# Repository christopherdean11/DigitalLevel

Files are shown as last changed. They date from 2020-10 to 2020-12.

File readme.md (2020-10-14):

# Digital LED Level
Custom PCB for using an accelerometer as a level with LED indicators. Scope is small to encourage getting to the finish line but has enough hardware features to come up with createive software ideas. 

## Goals
Overall: Create a PCB from scratch that can display multiple LED patterns  
- [x] Select a MCU - STM32F030F4
- [x] Design a PCB
- [x] Fab the PCB
- [x] Populate the PCB
- [x] Code and test the PCB

## Vender Documentation
### Datasheets:
* MCU - [STM32F030F4](https://www.st.com/resource/en/datasheet/stm32f030f4.pdf), [Reference Manual](https://www.st.com/resource/en/reference_manual/dm00091010-stm32f030x4x6x8xc-and-stm32f070x6xb-advanced-armbased-32bit-mcus-stmicroelectronics.pdf)
* 3.3V LDO - [MIC5504-3.3](https://www.microchip.com/wwwproducts/en/MIC5504)
* Accelerometer - [ADXL343](https://www.analog.com/media/en/technical-documentation/data-sheets/ADXL343.pdf)
* Acceleromter Breakout [Adafruit ADXL343 Breakout](https://learn.adafruit.com/adxl343-breakout-learning-guide/downloads)

### Guides / App Notes / Manuals:
* [STM32 Boot Options](https://www.st.com/content/ccc/resource/technical/document/application_note/b9/9b/16/3a/12/1e/40/0c/CD00167594.pdf/files/CD00167594.pdf/jcr:content/translations/en.C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)
* [Getting Started with STM32F030xx Hardware Development](https://www.st.com/content/ccc/resource/technical/document/application_note/91/66/2d/8c/f9/b5/47/55/DM00089834.pdf/files/DM00089834.pdf/jcr:content/translations/en.D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)
* [STM32F3 Discovery User Manual](https://www.st.com/content/ccc/resource/technical/document/user_manual/8a/56/97/63/8d/56/41/73/DM00063382.pdf/files/DM00063382.pdf/jcr:content/translations/en.DM0006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) (Initially used as a programmer, later replaced with standalone ST-LINK V2 USB dongle)

## Design Process
See [Hardware Design](pcb/readme.md) for hardware design process.  
Software Design readme coming soon.

## Features
#### Hardware
* 9 LEDs
* STM32F0
* Acceleromter
* 2 push-buttons
  - 1 hardwired to GPIO
  - 1 wired through a jumper to a GPIO (shared with INT1 on accelerometer)

#### Software
* LED cycle patterns with speed and direction adjustable with push-buttons

---
## Ideas for rev1
* Add a switch on the vcc input 
* Add smt LED on 3V3
* Just get the thing professionally assembled
* Would be nice to power from batteries, perhaps need a nice connector for that
* micro usb for power in connector?
* input voltage protection
* want to be able to control LED brightness
  - could try to find a suitable LED driver
  - could just add a PMOS inline with Vled for pwm-ing
  - could pwm the GPIOs but I don't think that would wok because PWM-ing the GPIO would block execution unless it was hardware timed somehow

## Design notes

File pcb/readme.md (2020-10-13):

# Hardware Design Process
## MCU Requirements
### Select an MCU
Initially thought about picking an STM32G0 series for low-cost, but after looking into it more, the STM32F0 series is not much more when buying low quantity, seems to be more popular, has extensive documentation, and the STM32F and STM32L series parts are already library components in Kicad.  
Another considerations was a package that lends itself to hand soldering.  With all of these in mind, I selected the [STM32F030F4](https://www.st.com/en/microcontrollers-microprocessors/stm32f030f4.html) in 20-pin TSSOP at approx. $1.23/unit.

###  I/O
This requires some time in STM Cube IDE to verify pinout and pin options to get a feel for what the board can look like.  We can easily get 8 GPIO outputs for LEDs with this MCU.  The [STM32F030F4](https://www.st.com/en/microcontrollers-microprocessors/stm32f030f4.html) comes in a 20pin TSSOP (this project will be hand soldered), with 12 GPIO available on PORTA + PB1 for 13 GPIO pins.
###  Programming
Another big item is how to program the MCU.  It looks like the STM32F030F4 has SWD (I beleive all ARM MCUs have this) support, so I should be able to connect with ST-LINK using SWD pins.  The F3 discovery board has an option to disconnect the actual dev board section from the ST-LINK section and use ST-LINK to program another board.  This will be a good starting point for programming. So the board will need to have the SWD pins broken out to headers.  

Tie BOOT0 to GND for normal operation and programming with SWD. See [this forum page](https://community.st.com/s/question/0D50X00009XkYDuSAN/hi-what-is-boot0-in-stm32).  Could tie it to a resitor to GND to leave door open to overdrive it if needed for some reason.  

The pinout for the SWD connector on the F3 Discovery board is available in [this document](https://www.st.com/content/ccc/resource/technical/document/user_manual/8a/56/97/63/8d/56/41/73/DM00063382.pdf/files/DM00063382.pdf/jcr:content/translations/en.DM0006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), page 16
Pins required: 
* VDD
* SWCLK
* GND
* SWDIO
* NRST - **NOTE:Solder bridge SB7 must be open to use NRST pin to control another device**

*Note: Eventually gave up with the F3 Discovery and orered a standalone ST-LINK V2 dongle, seems to just be easier*

## PCB Requirements:
- As small as reasonably possible to save cost
- series of LEDs in a row at one end
- SWD programming/debugging pins broken out
- At least 1 push button to cycle through LED options
- Acceleromter to do I2C comms and for LED patterns  

##  PCB Design Process:
* [x] Open CubeIDE to start a project with the STM32F030F4 and set up the pin configurations.
* [x] Add the MCU to a new design in Kicad.
* [x] Refer to the CubeIDE for the desired pin configuration.  Break out the SWD pins to headers and strap the BOOT pin.
* [x] Add some LEDs and a push button and wire it up.
* [x] Research and find an acceptable accelerometer.  Low cost I2C capable and hand-solerable.
* [x] Research and select a 3.3V regulator to power from 5V.

### Power
Plan is to power the board with 5V DC from a wall wart and regulate it to 3.3V.  Since this isn't powered by a battery, power efficiency isn't really a concern on this project (save that futuer versions), so an LDO will be fine, gets the job done and is dead simple to add to a PCB.  
#### Selecting 3.3V Regulator:
Just filter on digikey/mouser for 3.3V LDO. Found [MIC5504-3.3YM5](https://www.microchip.com/wwwproducts/en/MIC5504) for 3.3V at 300mA and 2% initial accuracy. VIN up to 5.5V. 
#### LED Power Consumption
9 LEDs at 15mA = 135mA  
Total allowed GPIO sourcing current for STM32F030F4 is 80mA (see page 44 in datasheet)  
*Redesigned board so LEDs are powered by the VDD rail and turned on off by GPIOs with an NMOS.*

### Acceleromoter
Needed a breakout board because all acceleromters have packages that do not lend themselves to hand-soldering.  The ADXL343 breakout from Adafruit is reasonbly priced and uses a quality acceleromter. 
Some notes: 
* Has a level shifter on board, may need to remove/jump over those but do not expect a problem
* See pg 16 of [ADXL3434 datasheet](https://www.analog.com/media/en/technical-documentation/data-sheets/ADXL343.pdf) for I2C addresses and address for Read/Write

| SDO/ALT_ADDRESS Pin | 7 bit address | Read Address | Write Address |  
| --- | --- | ---- | --- |
| GND | 0x53| 0xA6 | 0xA7 |

I2C address are 7-bit, and the least-signficant bit (LSB) is used to determine if the transaction is a read or write.

## PCB Layout
Begin layout of the design and revise as needed.
### Layout Process
1. Get everything in roughly the desired position. See how it looks, revise layout and schematic as needed.
   - I want all the LEDs in a nice row on the edge, so I changed the schematic to put LED current limit resistors between LED and NMOS and moved the current sense solder bridges for LED1 and LED5 for the same reason.  
1. Move on to routing power and ground after initial revisions are complete and rough layout is acceptable.
   - 2 Layer board
   - Ground plane as bottom layer, only use for routing when necessary to jump under existing traces
   - Run power along the edge of the board for LEDs and SW1, SW2, and wrap around to power acceleromter
   - This is not a high-speed or high-precision board, routing will be as good as it can be with 2 layers
## PCB Bring-Up Plan
Populate minimally requried components to get a program onto the board and show a sign of life.  
* Header pins, U1, U2, Boot resistor, decoupling caps, and LED2
* Run a program to blink LED2 to prove communication

Once that is working populate remainder of board and run a progressive blink routine to validate each LED.

## Experience Notes
* Almost forgot to add decoupling caps, researched and added those to the design as per the "Getting Started with STM32F030xx Hardware Development" link above.  
* Just noticed there is a "hand-solder" optional footprint for SMT components in KiCAD, and since I plan to hand solder, I will have to change all the footprints to those or I will probably wish I did.
* Board ordered on Feb 28 via oshpark
* Parts ordered on Feb 29 via mouser  

---

## Board Bring-up

*Eventually resolved these issues below and can talk to the board. Still not clear what the fix truly was, but I bought a standalone ST-LINK V2 USB dongle, updated STM CubeIDE to the latest, and completely discarded the Cube code project and started a Cube project, and all seems to be well.  The program downloads to the micro and the debugger works. Original debugging notes kept here.*

#### Original Debug Notes
* Trying to program using F3Discovery board as an ST-LINK and getting 

> Error message from debugger back end:  
> Load failed  
> Failed to execute MI command:  
> load /Users/christopherdean/Dev/stm32/LED_Level/code/Debug/Digital_Level.elf   
>  
> Error message from debugger back end:  
> Load failed  
> Load failed  

* Checked current on 3V3 rail (not using 3.3V regulator) and see it at ~1.3mA for a second or two, and then jump to ~1.8mA or 2mA
* [This schematic](https://easyeda.com/r3bers/STM32F103C8T6-Test-Board) shows pullup/down resistors on SWCLKS/SWDIO 
  - other posts online say the uc should have internal pullup/downs that are sufficient..

* Command to run the debugger from command line:
navigate to  
```
/Applications/STM32CubeIDE.app/Contents/Eclipse/plugins/com.st.stm32cube.ide.mcu.externaltools.stlink-gdb-server.macos64_1.3.0.202002181050/tools/bin
```
and run
```
./ST-LINK_gdbserver -d -v -cp /Applications/STM32CubeIDE.app/Contents/Eclipse/plugins/com.st.stm32cube.ide.mcu.externaltools.cubeprogrammer.macos64_1.3.0.202002181050/tools/bin
```

When I run it to program my board:
```
STMicroelectronics ST-LINK GDB server. Version 5.5.0
Copyright (c) 2019, STMicroelectronics. All rights reserved.

Starting server with the following options:
        Persistent Mode            : Disabled
        Logging Level              : 31
        Listen Port Number         : 61234
        Status Refresh Delay       : 15s
        Verbose Mode               : Enabled
        SWD Debug                  : Enabled

Target connection mode: Default
Target connection failed. Try connecting under reset
Target connection failed
Target unknown error 19

Error in initializing ST-LINK device.
Reason: Unknown. Please check power and cabling to target.
```

When I install the jumpers on the F3DISCOVERY board to use the ST-LINK to program the discovery board (and not just as an ST-LINK for external things), I see this:
```
STMicroelectronics ST-LINK GDB server. Version 5.5.0
Copyright (c) 2019, STMicroelectronics. All rights reserved.

Starting server with the following options:
        Persistent Mode            : Disabled
        Logging Level              : 31
        Listen Port Number         : 61234
        Status Refresh Delay       : 15s
        Verbose Mode               : Enabled
        SWD Debug                  : Enabled

Target connection mode: Default
Hardware watchpoint supported by the target 
COM frequency = 4000 kHz
ST-LINK Firmware version : V2J36M26
Device ID: 0x422
PC: 0x80007f8
ST-LINK device status: HALT_MODE
ST-LINK detects target voltage = 2.91 V
ST-LINK device status: HALT_MODE
ST-LINK device initialization OK
Waiting for debugger connection...
Waiting for connection on port 61234...
```
while it wait for a `gdb` process to connect to it

Maybe my microcontrollers are toasted?
Maybe next step is to solder one to a breakout board and try to program it on a breadboard?

Borrowed an STM32 USB programmer from a friend, got a new error about part is LOCKUP and debugger timed out.  Thought maybe finally clicking on the "Update CubeIDE" button might help. Get 1.4.2 installed and now the debugger won't even startup, just opens a window with 
```
ST-LINK Server is required to start the debug session. Download from st.com
```
Ok. Download. Install. No change. Restart the IDE. No change. :( 
This forum post suggests downgrading from 1.4.2 to 1.4.0 to get it to work. Ugh.
https://community.st.com/s/question/0D53W00000GWQKn/how-can-stlink-server-be-installed-for-use-by-stm32cubeide-

Tried to manually start the gdb session from the terminal with help here https://jacobmossberg.se/posts/2017/01/17/use-gdb-on-arm-assembly-program.html
it appeared to work and even saw `ST-LINK device status: RUN_MODE` but my board was still not working, perhaps a fundamental HW issue I just don't see. 

NRST pin is tied to the NRST pin on the SWD jumper but otherwise is floating.  It is supposed to be connected to a 40k ohm (typ) pullup internally.  There is a recommendation for a 0.1uF external capacitor to prevent parasitic resets, which is missing from the PCB design.  

#### Other Debugging Ideas
Maybe try the i2c lines as usart data lines for programming?
http://eleceng.dit.ie/frank/arm/STM32F030ISP/index.html

Maybe try after driving boot pin high:
https://electronics.stackexchange.com/questions/410386/stm32f0-boot0-pin-and-swd-programming

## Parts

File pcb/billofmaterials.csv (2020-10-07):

Id | Designator | Package | Quantity | Designation | Supplier and ref
1 | R10 | R_0603_1608Metric_Pad1.05x0.95mm_HandSolder | 1 | R
2 | R9,R8,R7,R6,R4,R3,R2,R1 | R_0603_1608Metric_Pad1.05x0.95mm_HandSolder | 8 | 100
3 | R5 | R_0603_1608Metric_Pad1.05x0.95mm_HandSolder | 1 | 82
4 | U3 | ADXL343_Breakout | 1 | ADXL343_Breakout
5 | U2 | SOT-23-5 | 1 | MIC5504-3.3YM5
6 | D9,D1,D2,D3,D4,D5,D6,D7,D8 | LED_D5.0mm | 9 | LED
7 | J1 | PinHeader_1x05_P2.54mm_Vertical | 1 | Conn_SWD
8 | J2 | PinHeader_1x02_P2.54mm_Vertical | 1 | Conn_VIN
9 | Q1,Q2,Q3,Q4,Q5,Q6,Q7,Q8,Q9 | SOT-23 | 9 | 2N7002
10 | SW1,SW2 | SW_PUSH_6mm | 2 | SW_Push
11 | U1 | TSSOP-20_4.4x6.5mm_P0.65mm | 1 | STM32F030F4Px
12 | J3 | PinHeader_1x03_P2.54mm_Vertical | 1 | Conn_SW_INT
13 | C1 | C_0603_1608Metric_Pad1.05x0.95mm_HandSolder | 1 | 100n
14 | C2 | C_1206_3216Metric_Pad1.42x1.75mm_HandSolder | 1 | 4.7u
15 | C3 | C_0603_1608Metric_Pad1.05x0.95mm_HandSolder | 1 | 10n
16 | C4 | C_1206_3216Metric_Pad1.42x1.75mm_HandSolder | 1 | 1u
17 | C5,C6 | C_0603_1608Metric_Pad1.05x0.95mm_HandSolder | 2 | 1u
18 | SB1,SB2 | R_0201_0603Metric | 2 | 0

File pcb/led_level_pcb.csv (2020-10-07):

Reference | Value | Footprint | Datasheet
U1 | STM32F030F4Px | Package_SO:TSSOP-20_4.4x6.5mm_P0.65mm | http://www.st.com/st-web-ui/static/active/en/resource/technical/document/datasheet/DM00088500.pdf
D1 | LED | LED_THT:LED_D5.0mm | ~
R10 | R | Resistor_SMD:R_0603_1608Metric_Pad1.05x0.95mm_HandSolder | ~
J1 | Conn_SWD | Connector_PinHeader_2.54mm:PinHeader_1x05_P2.54mm_Vertical | ~
SW1 | SW_Push | Button_Switch_THT:SW_PUSH_6mm
SW2 | SW_Push | Button_Switch_THT:SW_PUSH_6mm
U2 | MIC5504-3.3YM5 | Package_TO_SOT_SMD:SOT-23-5 | http://ww1.microchip.com/downloads/en/DeviceDoc/MIC550X.pdf
U3 | ADXL343_Breakout | footprints:ADXL343_Breakout
J3 | Conn_SW_INT | Connector_PinHeader_2.54mm:PinHeader_1x03_P2.54mm_Vertical | ~
R1 | 100 | Resistor_SMD:R_0603_1608Metric_Pad1.05x0.95mm_HandSolder | ~
Q1 | 2N7002 | Package_TO_SOT_SMD:SOT-23 | https://www.fairchildsemi.com/datasheets/2N/2N7002.pdf
Q2 | 2N7002 | Package_TO_SOT_SMD:SOT-23 | https://www.fairchildsemi.com/datasheets/2N/2N7002.pdf
D2 | LED | LED_THT:LED_D5.0mm | ~
D3 | LED | LED_THT:LED_D5.0mm | ~
Q3 | 2N7002 | Package_TO_SOT_SMD:SOT-23 | https://www.fairchildsemi.com/datasheets/2N/2N7002.pdf
Q4 | 2N7002 | Package_TO_SOT_SMD:SOT-23 | https://www.fairchildsemi.com/datasheets/2N/2N7002.pdf
D4 | LED | LED_THT:LED_D5.0mm | ~
R4 | 100 | Resistor_SMD:R_0603_1608Metric_Pad1.05x0.95mm_HandSolder | ~
Q5 | 2N7002 | Package_TO_SOT_SMD:SOT-23 | https://www.fairchildsemi.com/datasheets/2N/2N7002.pdf
D5 | LED | LED_THT:LED_D5.0mm | ~
R5 | 82 | Resistor_SMD:R_0603_1608Metric_Pad1.05x0.95mm_HandSolder | ~
D6 | LED | LED_THT:LED_D5.0mm | ~
R6 | 100 | Resistor_SMD:R_0603_1608Metric_Pad1.05x0.95mm_HandSolder | ~
Q6 | 2N7002 | Package_TO_SOT_SMD:SOT-23 | https://www.fairchildsemi.com/datasheets/2N/2N7002.pdf
Q7 | 2N7002 | Package_TO_SOT_SMD:SOT-23 | https://www.fairchildsemi.com/datasheets/2N/2N7002.pdf
D7 | LED | LED_THT:LED_D5.0mm | ~
R7 | 100 | Resistor_SMD:R_0603_1608Metric_Pad1.05x0.95mm_HandSolder | ~
D8 | LED | LED_THT:LED_D5.0mm | ~
R8 | 100 | Resistor_SMD:R_0603_1608Metric_Pad1.05x0.95mm_HandSolder | ~
Q8 | 2N7002 | Package_TO_SOT_SMD:SOT-23 | https://www.fairchildsemi.com/datasheets/2N/2N7002.pdf
Q9 | 2N7002 | Package_TO_SOT_SMD:SOT-23 | https://www.fairchildsemi.com/datasheets/2N/2N7002.pdf
D9 | LED | LED_THT:LED_D5.0mm | ~
R9 | 100 | Resistor_SMD:R_0603_1608Metric_Pad1.05x0.95mm_HandSolder | ~
R3 | 100 | Resistor_SMD:R_0603_1608Metric_Pad1.05x0.95mm_HandSolder | ~
R2 | 100 | Resistor_SMD:R_0603_1608Metric_Pad1.05x0.95mm_HandSolder | ~
J2 | Conn_VIN | Connector_PinHeader_2.54mm:PinHeader_1x02_P2.54mm_Vertical | ~
C1 | 100n | Capacitor_SMD:C_0603_1608Metric_Pad1.05x0.95mm_HandSolder | ~
C2 | 4.7u | Capacitor_SMD:C_1206_3216Metric_Pad1.42x1.75mm_HandSolder | ~
C3 | 10n | Capacitor_SMD:C_0603_1608Metric_Pad1.05x0.95mm_HandSolder | ~
C4 | 1u | Capacitor_SMD:C_1206_3216Metric_Pad1.42x1.75mm_HandSolder | ~
C5 | 1u | Capacitor_SMD:C_0603_1608Metric_Pad1.05x0.95mm_HandSolder | ~
C6 | 1u | Capacitor_SMD:C_0603_1608Metric_Pad1.05x0.95mm_HandSolder | ~
SB1 | 0 | Resistor_SMD:R_0201_0603Metric | ~
SB2 | 0 | Resistor_SMD:R_0201_0603Metric | ~

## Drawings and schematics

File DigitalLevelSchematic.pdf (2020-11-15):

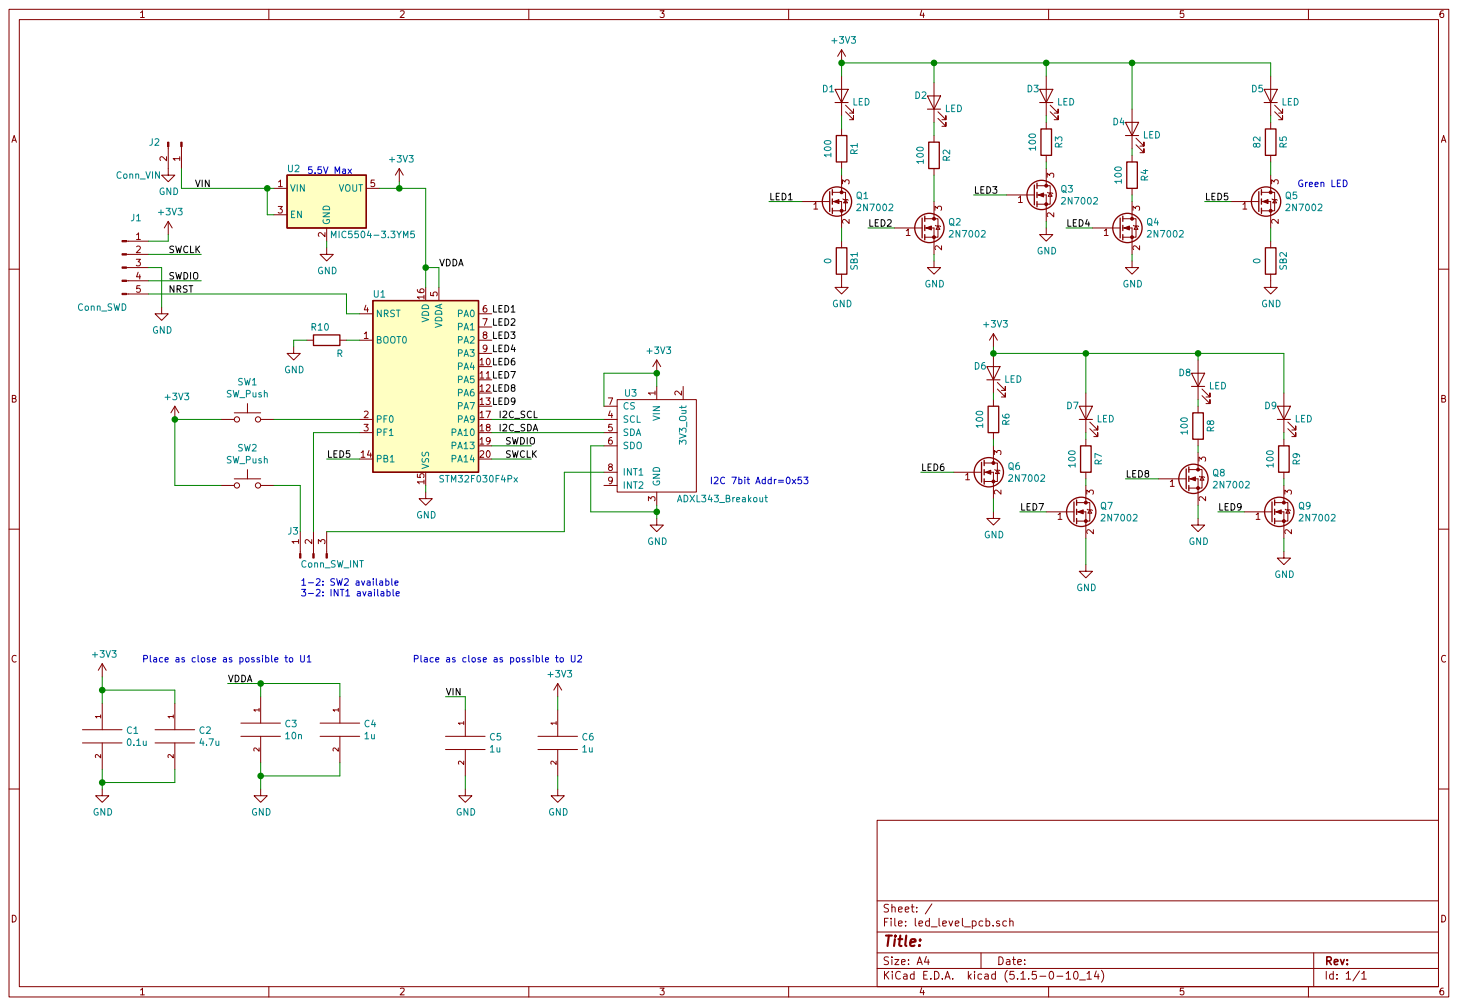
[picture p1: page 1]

3 SCL 4 SDA 5 SDO 6 CS 7

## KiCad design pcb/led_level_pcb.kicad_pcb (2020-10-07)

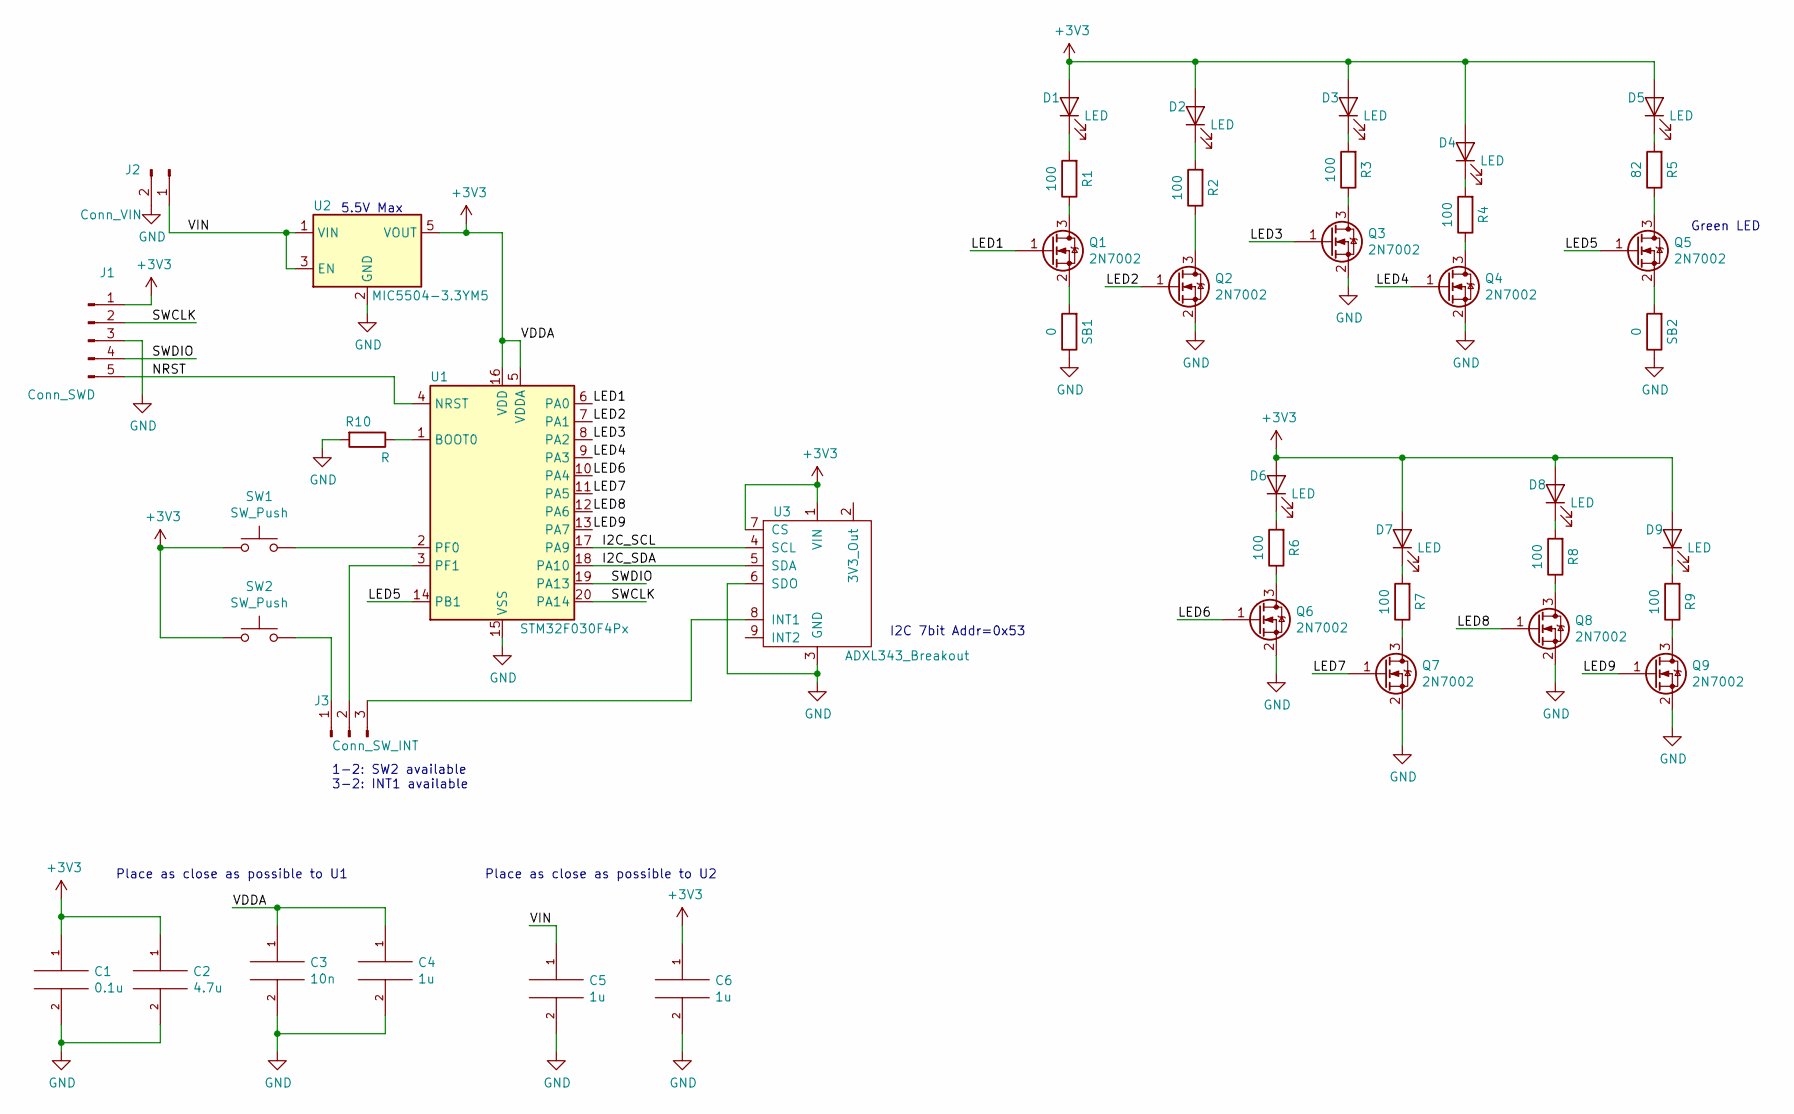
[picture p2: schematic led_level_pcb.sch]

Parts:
C1: 0.1u; C_0603_1608Metric_Pad1.05x0.95mm_HandSolder
C2: 4.7u; C_1206_3216Metric_Pad1.42x1.75mm_HandSolder
C3: 10n; C_0603_1608Metric_Pad1.05x0.95mm_HandSolder
C4: 1u; C_1206_3216Metric_Pad1.42x1.75mm_HandSolder
C5, C6: 1u; C_0603_1608Metric_Pad1.05x0.95mm_HandSolder
D1, D2, D3, D4, D5, D6, D7, D8, D9: LED; LED_D5.0mm
J1: Conn_SWD; PinHeader_1x05_P2.54mm_Vertical
J2: Conn_VIN; PinHeader_1x02_P2.54mm_Vertical
J3: Conn_SW_INT; PinHeader_1x03_P2.54mm_Vertical
Q1, Q2, Q3, Q4, Q5, Q6, Q7, Q8, Q9: 2N7002; SOT-23
R1, R2, R3, R4, R6, R7, R8, R9: 100; R_0603_1608Metric_Pad1.05x0.95mm_HandSolder
R5: 82; R_0603_1608Metric_Pad1.05x0.95mm_HandSolder
R10: R; R_0603_1608Metric_Pad1.05x0.95mm_HandSolder
SB1, SB2: 0; R_0201_0603Metric
SW1, SW2: SW_Push; SW_PUSH_6mm
U1: STM32F030F4Px; TSSOP-20_4.4x6.5mm_P0.65mm
U2: MIC5504-3.3YM5; SOT-23-5
U3: ADXL343_Breakout

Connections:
+3V3: C1.1, C2.1, C3.1, C4.1, C6.1, D1.2 (A), D2.2 (A), D3.2 (A), D4.2 (A), D5.2 (A), D6.2 (A), D7.2 (A), D8.2 (A), D9.2 (A), J1.1, SW1.1, SW2.1, U1.5 (VDDA), U1.16 (VDD), U2.5 (VOUT), U3.1 (VIN), U3.7 (CS)
/I2C_SCL: U1.17 (PA9), U3.4 (SCL)
/I2C_SDA: U1.18 (PA10), U3.5 (SDA)
/LED1: Q1.1 (G), U1.6 (PA0)
/LED2: Q2.1 (G), U1.7 (PA1)
/LED3: Q3.1 (G), U1.8 (PA2)
/LED4: Q4.1 (G), U1.9 (PA3)
/LED5: Q5.1 (G), U1.14 (PB1)
/LED6: Q6.1 (G), U1.10 (PA4)
/LED7: Q7.1 (G), U1.11 (PA5)
/LED8: Q8.1 (G), U1.12 (PA6)
/LED9: Q9.1 (G), U1.13 (PA7)
/NRST: J1.5, U1.4 (NRST)
/SWCLK: J1.2, U1.20 (PA14)
/SWDIO: J1.4, U1.19 (PA13)
/VIN: C5.1, J2.1, U2.1 (VIN), U2.3 (EN)
GND: C1.2, C2.2, C3.2, C4.2, C5.2, C6.2, J1.3, J2.2, Q2.2 (S), Q3.2 (S), Q4.2 (S), Q6.2 (S), Q7.2 (S), Q8.2 (S), Q9.2 (S), R10.2, SB1.1, SB2.1, U1.15 (VSS), U2.2 (GND), U3.3 (GND), U3.6 (SDO)
unnamed: D1.1 (K), R1.2
unnamed: D2.1 (K), R2.2
unnamed: D3.1 (K), R3.2
unnamed: D4.1 (K), R4.2
unnamed: D5.1 (K), R5.2
unnamed: D6.1 (K), R6.2
unnamed: D7.1 (K), R7.2
unnamed: D8.1 (K), R8.2
unnamed: D9.1 (K), R9.2
unnamed: J3.1, SW2.2
unnamed: J3.2, U1.3 (PF1)
unnamed: J3.3, U3.8 (INT1)
unnamed: Q1.2 (S), SB1.2
unnamed: Q1.3 (D), R1.1
unnamed: Q2.3 (D), R2.1
unnamed: Q3.3 (D), R3.1
unnamed: Q4.3 (D), R4.1
unnamed: Q5.2 (S), SB2.2
unnamed: Q5.3 (D), R5.1
unnamed: Q6.3 (D), R6.1
unnamed: Q7.3 (D), R7.1
unnamed: Q8.3 (D), R8.1
unnamed: Q9.3 (D), R9.1
unnamed: R10.1, U1.1 (BOOT0)
unnamed: SW1.2, U1.2 (PF0)

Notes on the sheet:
I2C 7bit Addr=0x53
1-2: SW2 available 3-2: INT1 available
5.5V Max
Green LED
Place as close as possible to U1
Place as close as possible to U2

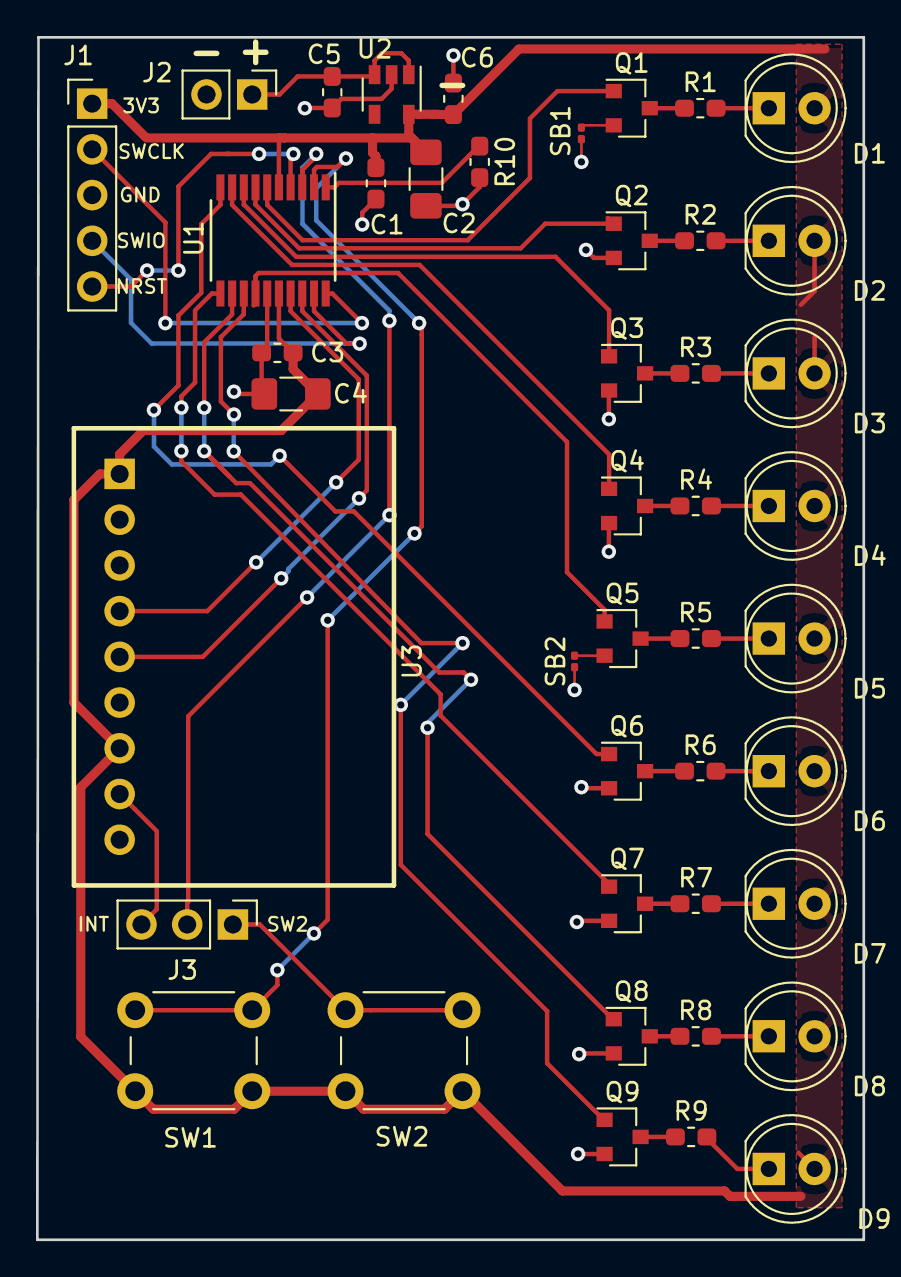
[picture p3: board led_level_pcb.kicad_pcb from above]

Board: 2 copper layers, 45.9 x 66.8 mm, 44 parts (0 on the bottom side), 42 nets.

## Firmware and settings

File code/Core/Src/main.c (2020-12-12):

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
/* Includes ------------------------------------------------------------------*/
#include "main.h"

/* USER CODE BEGIN Includes */
#include "accelerometer.h"
#include "led.h"
/* USER CODE END Includes */

I2C_HandleTypeDef hi2c1;

/* USER CODE BEGIN PV */

volatile uint32_t delay;
volatile uint8_t direction;
volatile uint8_t state;
volatile uint8_t accel_range;
volatile uint8_t activeAxis;
volatile int8_t sens_gain = 2;

/* USER CODE END PV */

void SystemClock_Config(void);
static void MX_GPIO_Init(void);
static void MX_I2C1_Init(void);
/* USER CODE BEGIN 0 */


void HAL_GPIO_EXTI_Callback(uint16_t GPIO_Pin){

	// don't need to check if readPin is high, it had to be to even get here
	if (GPIO_Pin == GPIO_PIN_0){
		// SW1 (shared with accel INT jumper)
		// adjust the delay/update rate
//		if (delay < 100){
//			delay = 100;
//		}else{
//			delay = 20;
//		}

		// adjust the LED sensitivity gain and blink the nth LED to show gain multiplier
		sens_gain*=2;
		if (sens_gain > 8){
			sens_gain = 1;
		}
		LED_disableAll();
		LED_blink_withDelay(sens_gain, 2, 200);

	}

	if (GPIO_Pin == GPIO_PIN_1) {
		// SW2
		// If jumper is set for ACCEL interrupts
		// this pin will go high indicating an interrupt was triggered on INT1
		uint8_t check = ACCEL_readReg(&hi2c1, 0x30); // read INT_SOURCE reg
		uint8_t dummy = check;
		// LED_blink_withDelay(9, 3, 100);
	}
}


/* USER CODE END 0 */

/**
  * @brief  The application entry point.
  * @retval int
  */
int main(void)
{
  /* MCU Configuration--------------------------------------------------------*/

  /* Reset of all peripherals, Initializes the Flash interface and the Systick. */
  HAL_Init();

  /* Configure the system clock */
  SystemClock_Config();

  /* Initialize all configured peripherals */
  MX_GPIO_Init();
  MX_I2C1_Init();
  /* Infinite loop */
  /* USER CODE BEGIN WHILE */
  delay = 100;
  direction = 0;
  state = 0;
  accel_range = 0;

  uint8_t check;
  ACCEL_verifyI2C(&hi2c1, ADXL343_ADDRESS, (uint8_t) 0, (uint8_t) 0xE5);
  ACCEL_setFullRes(&hi2c1, 0);
  ACCEL_setRange(&hi2c1, 0);
  ACCEL_enableMeasurements(&hi2c1);
  ACCEL_setTapThreshold(&hi2c1, 2, 2); // 4 * 62.5mg, 4*625us duration
  ACCEL_setTapAxes(&hi2c1, 1, 1, 1, 1);
  ACCEL_enableInterrupts(&hi2c1, 0, 1);

  check = ACCEL_readReg(&hi2c1, 0x2E); // INT_EN register
  check = ACCEL_readReg(&hi2c1, 0x1D); // THRES_TAP register

  LED_disableAll();

  activeAxis = ACCEL_X_ID;
  int8_t led;
  float g;
  uint8_t blink = 0;
  while (1)
    {
    /* USER CODE END WHILE */

    /* USER CODE BEGIN 3 */

  	  if (activeAxis == ACCEL_X_ID){
  		  g = ACCEL_getX(&hi2c1);
  	  }else if (activeAxis == ACCEL_Y_ID){
  		  g = ACCEL_getY(&hi2c1);
  	  }

  	  // LED position calc
  	  // center led + (g * num LEDs per side)
  	  led = 5 + (g*4*sens_gain);
  	  if (led > 9){
  		  led = 9;
  		  blink = 1;
  	  } else if (led < 1){
  		  led = 1;
  		  blink = 1;
  	  } else{
  		  blink = 0;
  	  }
  	  if (blink){
  		  LED_blink_withDelay(led, 2, 100);
  	  } else {
  		  LED_writeState(led, 1);
  	  }

  	  HAL_Delay(delay);
      LED_disableAll();

  }
  /* USER CODE END 3 */
}

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


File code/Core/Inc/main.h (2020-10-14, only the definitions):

#define SW0_Pin GPIO_PIN_0
#define SW0_GPIO_Port GPIOF
#define SW0_EXTI_IRQn EXTI0_1_IRQn
#define SW1_Pin GPIO_PIN_1
#define SW1_GPIO_Port GPIOF
#define SW1_EXTI_IRQn EXTI0_1_IRQn
#define LED1_Pin GPIO_PIN_0
#define LED1_GPIO_Port GPIOA
#define LED2_Pin GPIO_PIN_1
#define LED2_GPIO_Port GPIOA
#define LED3_Pin GPIO_PIN_2
#define LED3_GPIO_Port GPIOA
#define LED4_Pin GPIO_PIN_3
#define LED4_GPIO_Port GPIOA
#define LED6_Pin GPIO_PIN_4
#define LED6_GPIO_Port GPIOA
#define LED7_Pin GPIO_PIN_5
#define LED7_GPIO_Port GPIOA
#define LED8_Pin GPIO_PIN_6
#define LED8_GPIO_Port GPIOA
#define LED9_Pin GPIO_PIN_7
#define LED9_GPIO_Port GPIOA
#define LED5_Pin GPIO_PIN_1
#define LED5_GPIO_Port GPIOB

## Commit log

2020-10-07 board rev 0 as built
    [billofmaterials.csv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]
2020-10-08 add cart from mouser order
    [Mouser_Cart_Feb28.xlsx]
2020-10-10 replace code with new project files
    [DigitalLevel.ioc, main.c, main.h]
2020-10-31 got accel data on leds, bugfix in LED_disableAll
    [accelerometer.c, led.c, main.c]
2020-11-15 add schematic pdf
2020-12-12 add more accelerometer functions

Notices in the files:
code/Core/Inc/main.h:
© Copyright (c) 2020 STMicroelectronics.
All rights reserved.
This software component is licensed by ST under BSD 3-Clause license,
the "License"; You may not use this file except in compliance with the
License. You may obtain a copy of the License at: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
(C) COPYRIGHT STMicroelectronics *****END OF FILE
